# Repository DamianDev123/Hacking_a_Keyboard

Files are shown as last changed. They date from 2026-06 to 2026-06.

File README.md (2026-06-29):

# Hacking_a_Keyboard

Hacking_a_Keyboard is a 9 key macropad with a OLED display, and WS2812B LEDs. It runs KMK firmware.

---

## Features:
- 128×32 OLED display
- 4× WS2812B RGB LEDs
- 9 keys
---

## CAD Model:
Everything fits together using 6 M3 bolts and heat-set inserts:
- 4 for the case
- 2 for securing the PCB

It consists of 3 printed parts:
- Bottom case
- Top cover
Screenshot 2026-06-29 at 7 42 36 AM

Made in Onshape.

---

## PCB:
Designed in KiCad with silkscreen imported from Figma.

Schematic:
Screenshot 2026-06-29 at 8 33 09 AM

PCB:
Screenshot 2026-06-29 at 8 32 51 AM
---

## Firmware Overview:
This hackpad uses KMK firmware.

- 9 keys:
  - randoms keys

- RGB:
  - Gaming
    
- OLED display:
  - TODO

More features may be added later.

---

## BOM:
Everything needed to build the hackpad:

- 9× Cherry MX switches
- 9× DSA keycaps
- 4× M3×5×4 heat-set inserts
- 6× M3×16 SHCS bolts
- 9× 1N4148 DO-35 diodes
- 4× WS2812B LEDs
- 1× 0.91" 128×32 OLED display
- 1× Seeed XIAO RP2040
- 1× case (2 printed parts)

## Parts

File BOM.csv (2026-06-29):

Item | Required Qty | Component Description | Sourcing / Part Notes
1 | 1 | Seeed Studio XIAO RP2040 | Main Microcontroller Board (Unsoldered)
2 | 1 | 0.91" SSD1306 OLED Display | 128x32 Pixel Screen, I2C Interface (Pinout: GND-VCC-SCL-SDA)
4 | 9 | MX-Style Mechanical Switches | Keyswitches of choice
5 | 9 | Blank DSA Keycaps | White keycaps
6 | 4 | SK6812 MINI-E RGB LEDs | Reverse-mount addressable LEDs
7 | 6 | M3x16mm Screws | Enclosure fasteners
8 | 6 | M3x5x4mm Heatset Inserts | Brass threaded chassis inserts
9 | 9 | 1N4148 Diodes | Through-hole matrix diodes (Unused in direct pin layout)
10 | 1 | Soldering Iron Station | Required for assembly (Target temperature: 320°C - 350°C)

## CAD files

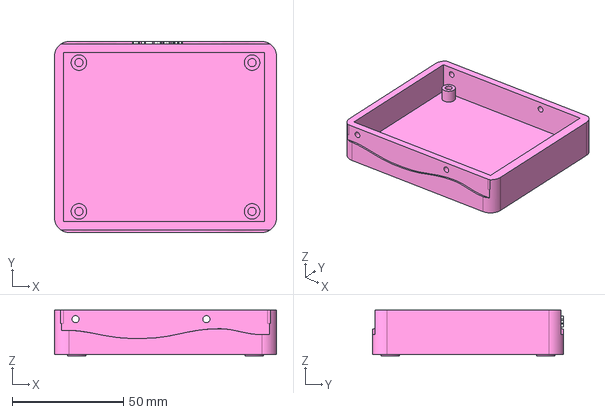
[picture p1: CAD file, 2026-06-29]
Production/Bottom.step
100.0 x 86.0 x 20.5 mm

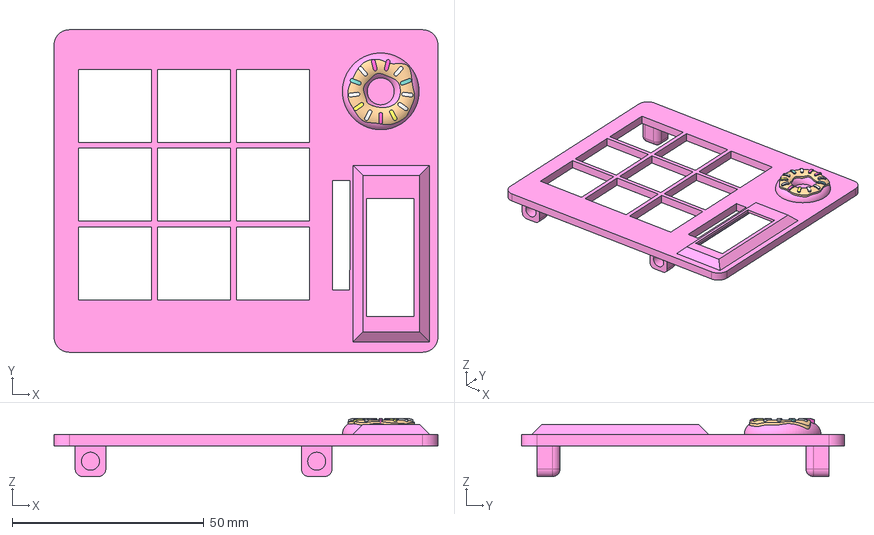
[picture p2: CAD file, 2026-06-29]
Production/Top.step
100.0 x 84.0 x 15.1 mm

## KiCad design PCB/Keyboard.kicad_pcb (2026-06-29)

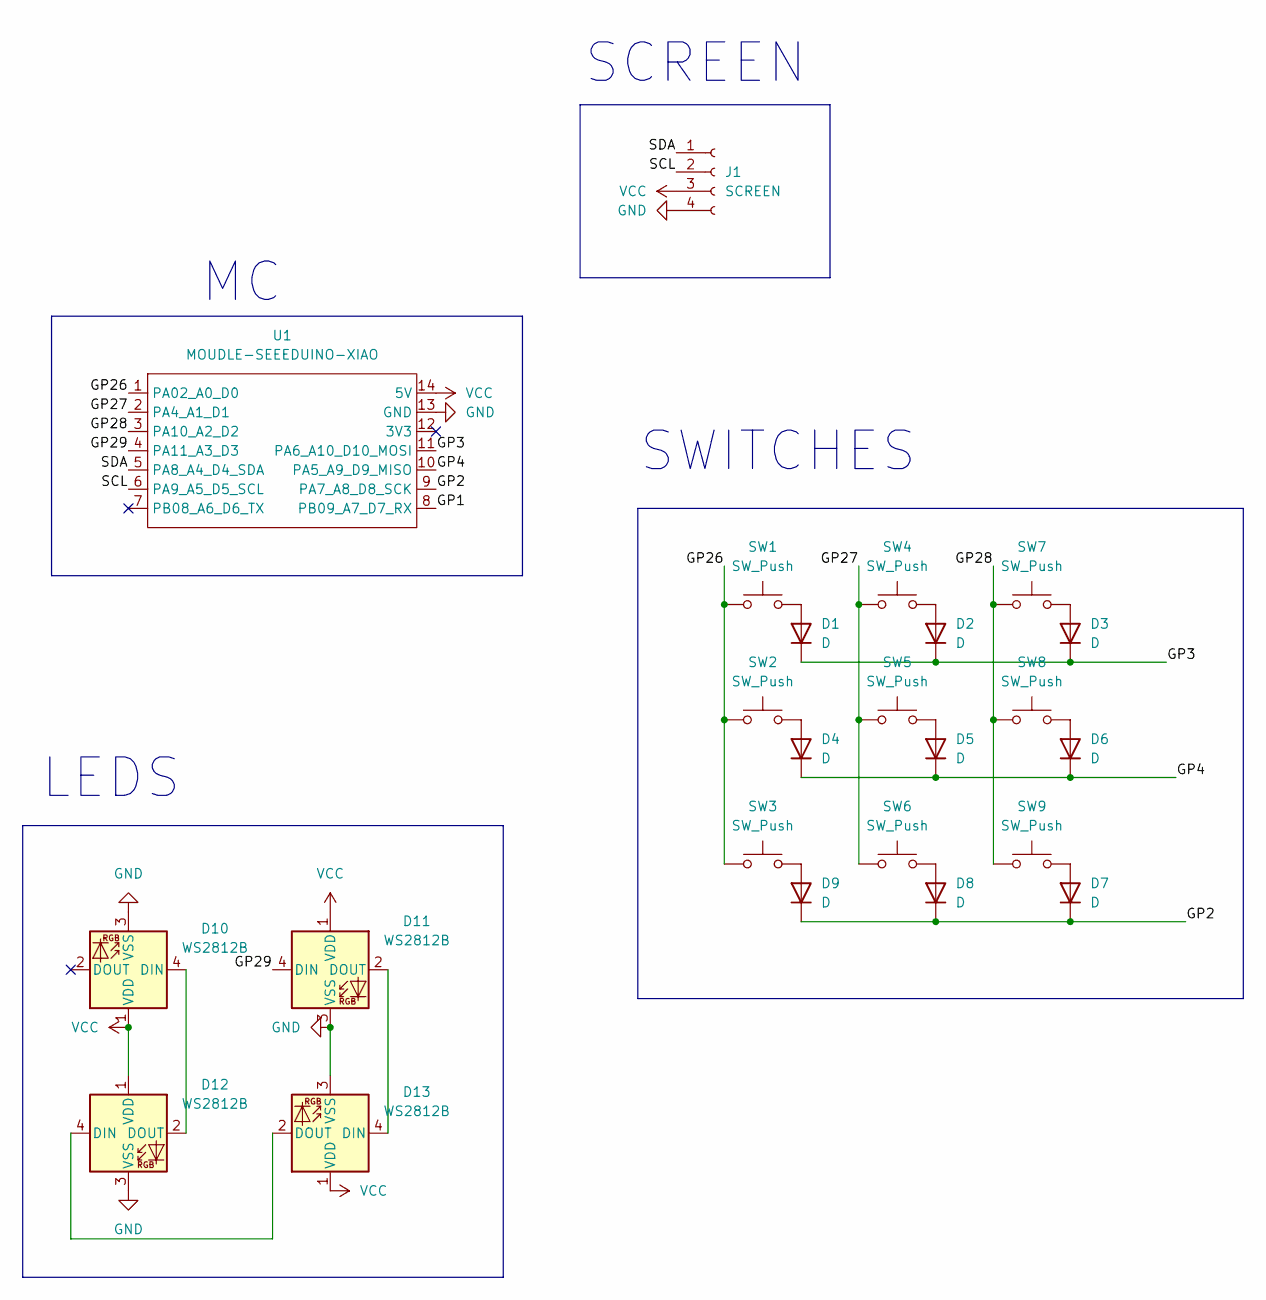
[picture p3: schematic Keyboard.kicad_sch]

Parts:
D1, D2, D3, D4, D5, D6, D7, D8, D9: D; D_DO-35_SOD27_P7.62mm_Horizontal
D10, D11, D12, D13: WS2812B; SK6812MINI-E_fixed
J1: SCREEN; PinSocket_1x04_P2.54mm_Vertical
SW1, SW2, SW3, SW4, SW5, SW6, SW7, SW8, SW9: SW_Push; SW_Cherry_MX_1.00u_PCB
U1: MOUDLE-SEEEDUINO-XIAO; XIAO-Generic-Hybrid-14P-2.54-21X17.8MM

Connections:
/GP1: U1.8 (PB09_A7_D7_RX)
/GP2: D7.1 (K), D8.1 (K), D9.1 (K), U1.9 (PA7_A8_D8_SCK)
/GP3: D1.1 (K), D2.1 (K), D3.1 (K), U1.11 (PA6_A10_D10_MOSI)
/GP4: D4.1 (K), D5.1 (K), D6.1 (K), U1.10 (PA5_A9_D9_MISO)
/GP26: SW1.1, SW2.1, SW3.1, U1.1 (PA02_A0_D0)
/GP27: SW4.1, SW5.1, SW6.1, U1.2 (PA4_A1_D1)
/GP28: SW7.1, SW8.1, SW9.1, U1.3 (PA10_A2_D2)
/GP29: D11.4 (DIN), U1.4 (PA11_A3_D3)
/SCL: J1.2, U1.6 (PA9_A5_D5_SCL)
/SDA: J1.1, U1.5 (PA8_A4_D4_SDA)
GND: D10.3 (VSS), D11.3 (VSS), D12.3 (VSS), D13.3 (VSS), J1.4, U1.13 (GND)
unnamed: D1.2 (A), SW1.2
unnamed: D2.2 (A), SW4.2
unnamed: D3.2 (A), SW7.2
unnamed: D4.2 (A), SW2.2
unnamed: D5.2 (A), SW5.2
unnamed: D6.2 (A), SW8.2
unnamed: D7.2 (A), SW9.2
unnamed: D8.2 (A), SW6.2
unnamed: D9.2 (A), SW3.2
unnamed: D10.4 (DIN), D12.2 (DOUT)
unnamed: D11.2 (DOUT), D13.4 (DIN)
unnamed: D12.4 (DIN), D13.2 (DOUT)
VCC: D10.1 (VDD), D11.1 (VDD), D12.1 (VDD), D13.1 (VDD), J1.3, U1.14 (5V)

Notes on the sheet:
LEDS
SCREEN
SWITCHES

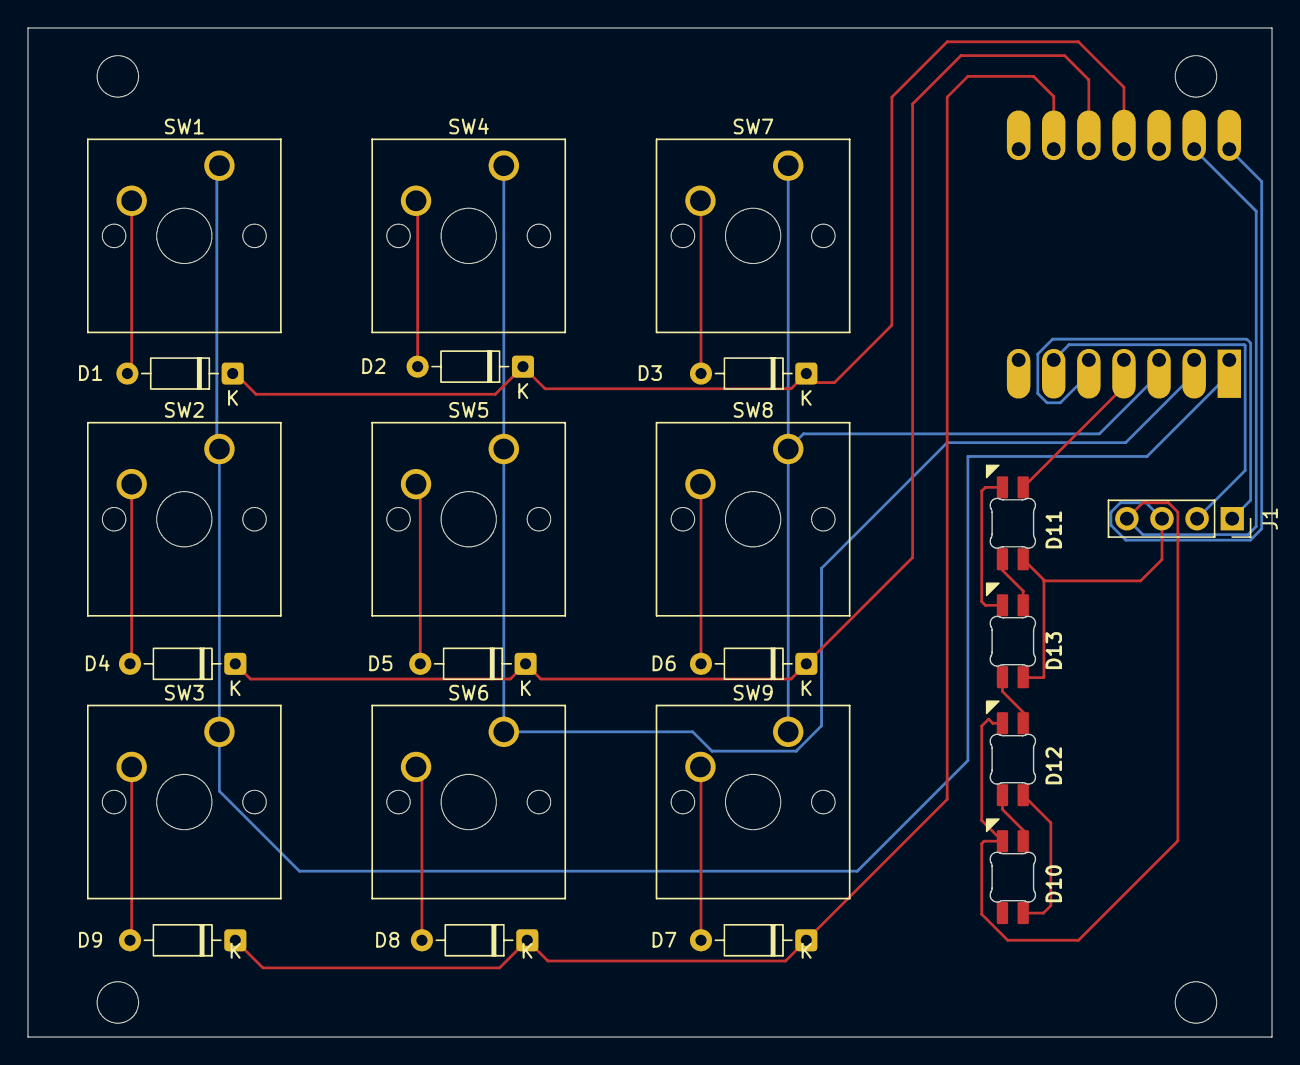
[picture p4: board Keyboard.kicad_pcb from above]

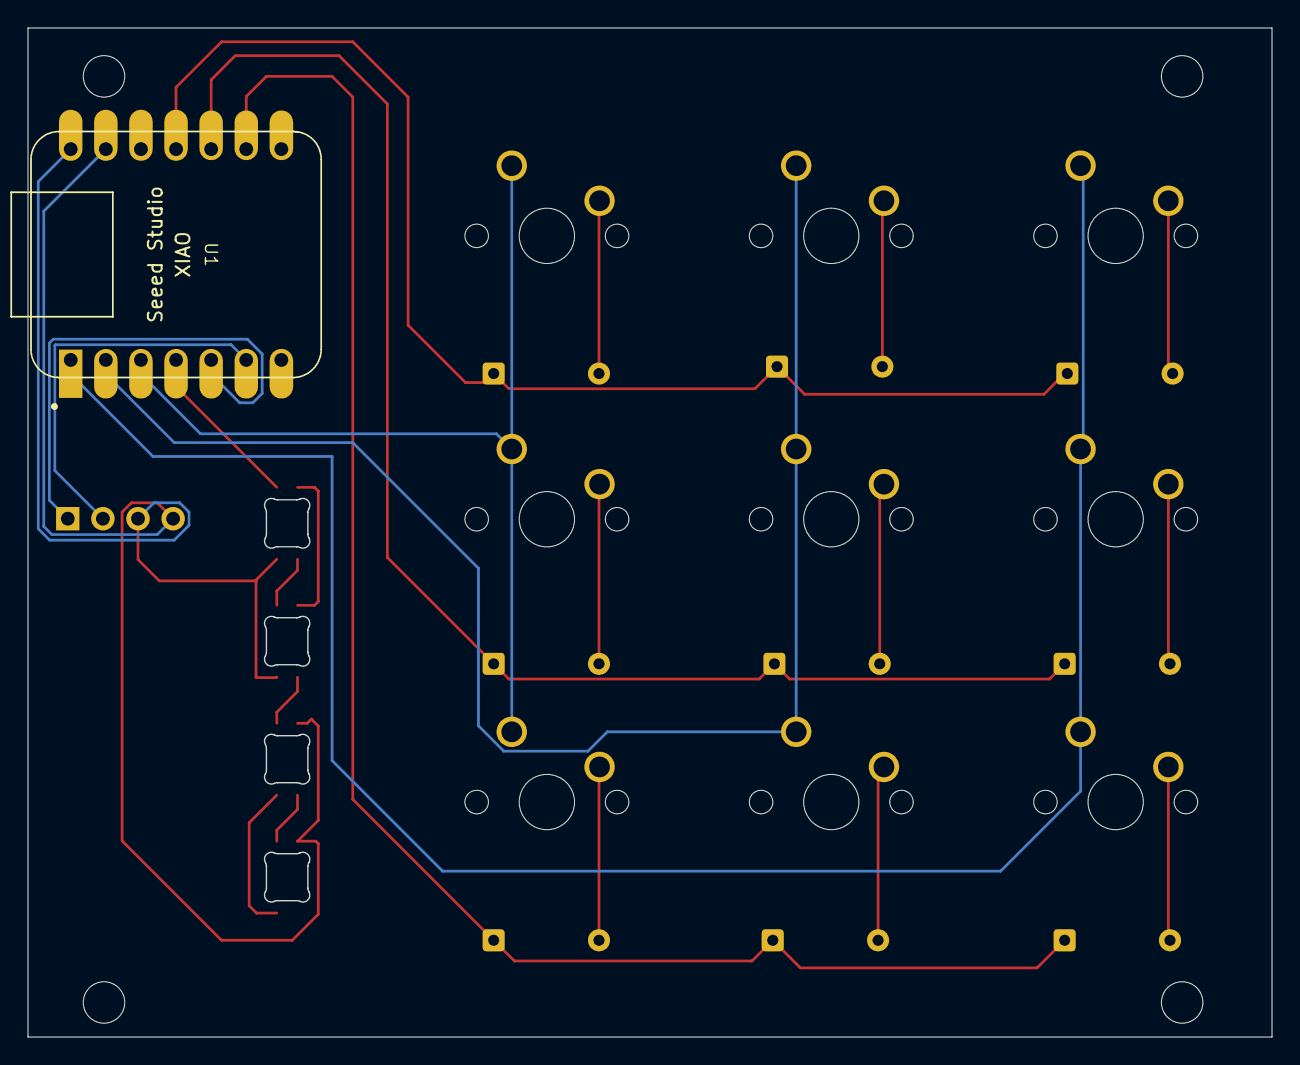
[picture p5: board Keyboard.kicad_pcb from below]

Board: 2 copper layers, 90.0 x 73.0 mm, 24 parts (5 on the bottom side), 23 nets.

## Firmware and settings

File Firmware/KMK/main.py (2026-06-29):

# DEAD CODE, NOT DONE!

print("Hackpad Testing!")

import board

from kmk.kmk_keyboard import KMKKeyboard
from kmk.keys import KC
from kmk.scanners import DiodeOrientation

# Extra features
from kmk.extensions.RGB import RGB


print(dir(board))

keyboard = KMKKeyboard()
keyboard.col_pins = (board.GP26, board.GP27,board.GP28)
keyboard.row_pins = (board.GP3, board.GP4, board.GP2)

keyboard.diode_orientation = DiodeOrientation.COL2ROW

# RGB imports
rgb = RGB(pixel_pin=board.GP29, num_pixels=4)
keyboard.extensions.append(rgb)

# TODO: add OLED display



keyboard.keymap = [
    [

        KC.F, KC.U, KC.C,
        KC.K, KC.G, KC.W,
        KC.O, KC.DOT, KC.P,
    ]
]


if __name__ == '__main__':
    keyboard.go()

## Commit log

2026-06-29 Revise README with Orpheuspad specificationsR
    Updated README to include details about Orpheuspad, its features, CAD model, PCB design, firmware overview, and BOM.
2026-06-29 Adjust PCB image size in README
    Updated PCB image dimensions in README.md.
